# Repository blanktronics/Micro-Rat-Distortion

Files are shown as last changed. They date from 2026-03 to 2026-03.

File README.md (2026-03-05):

# Overview
Micro Rat Distortion majorly influnced by Olinthus Designs mini effects.

The idea is simple, I wanted to challenge myself by trying to recreate an extremely small version of the ProCo Rat distortion.

My secondary challenge is I want to create something even smaller than the Olinthus Desgin effects.

So far the dimesions of my project mostly mimcs the Olinthus dimensions except my assembly is 50mils wider and 50 mils thinner.

Next steps are to just shrink shrink shrink.

If you would like to try this out for yourself, the KiCad project I've designed can found in this repository!

## Pictures
Here are some pictures of the progress so far.

|  |  |  |  |
| --- | --- | --- | --- |
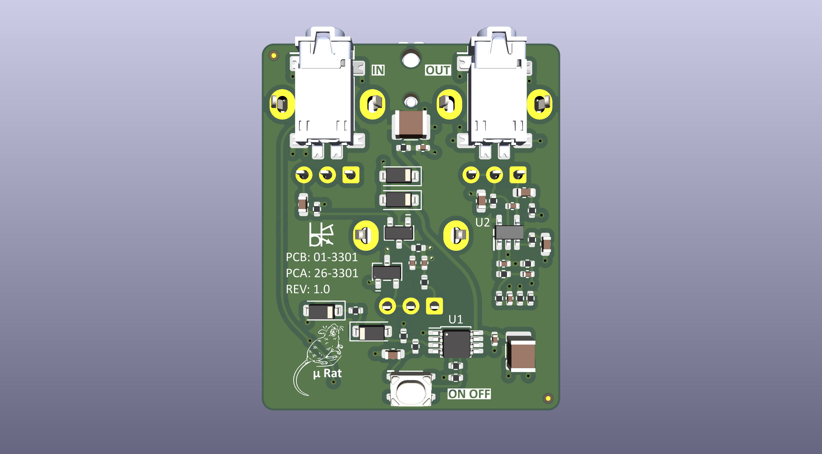
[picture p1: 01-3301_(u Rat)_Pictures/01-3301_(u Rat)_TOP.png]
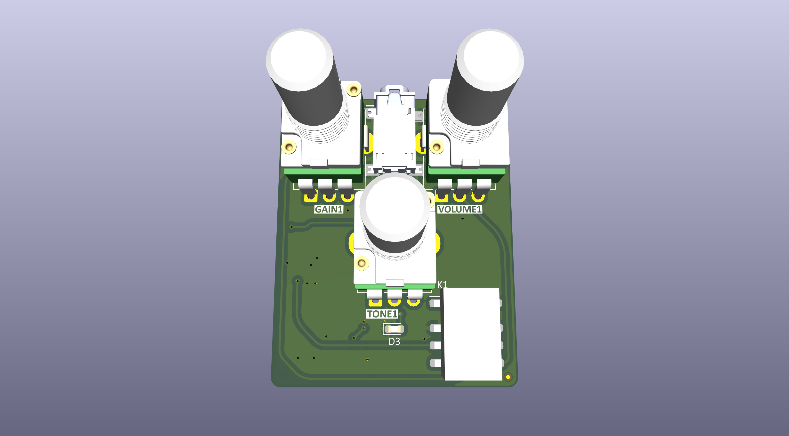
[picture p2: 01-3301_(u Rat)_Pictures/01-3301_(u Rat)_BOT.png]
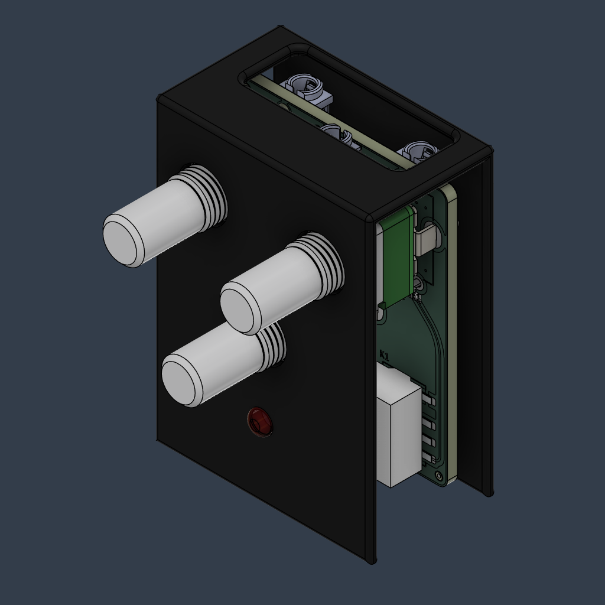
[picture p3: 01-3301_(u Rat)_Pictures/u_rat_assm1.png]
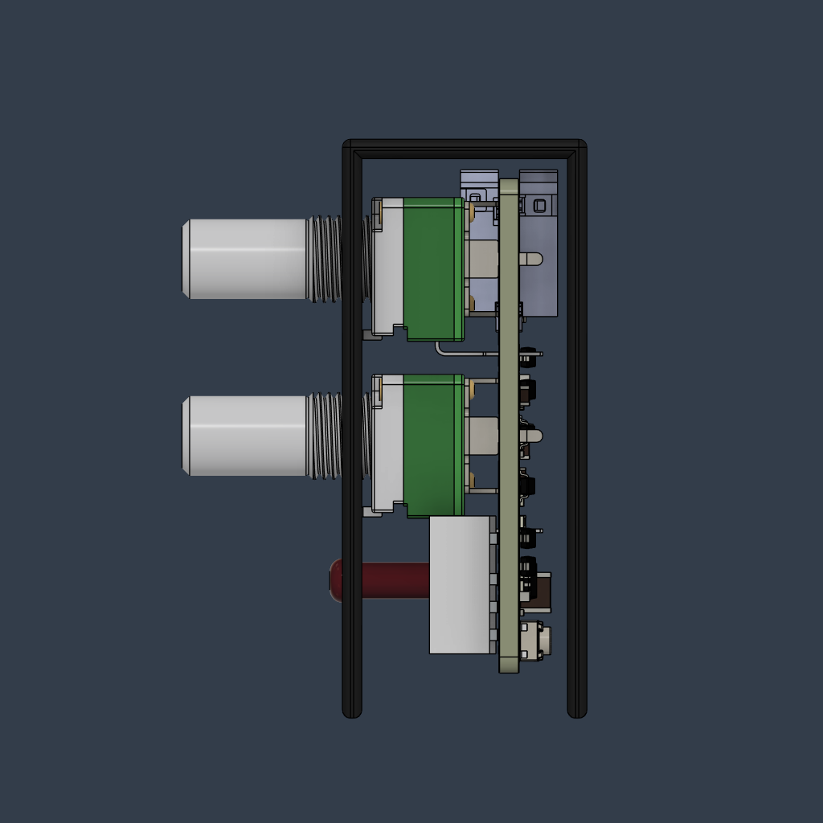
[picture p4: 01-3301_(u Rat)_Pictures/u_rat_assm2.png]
|  |  |  |  |
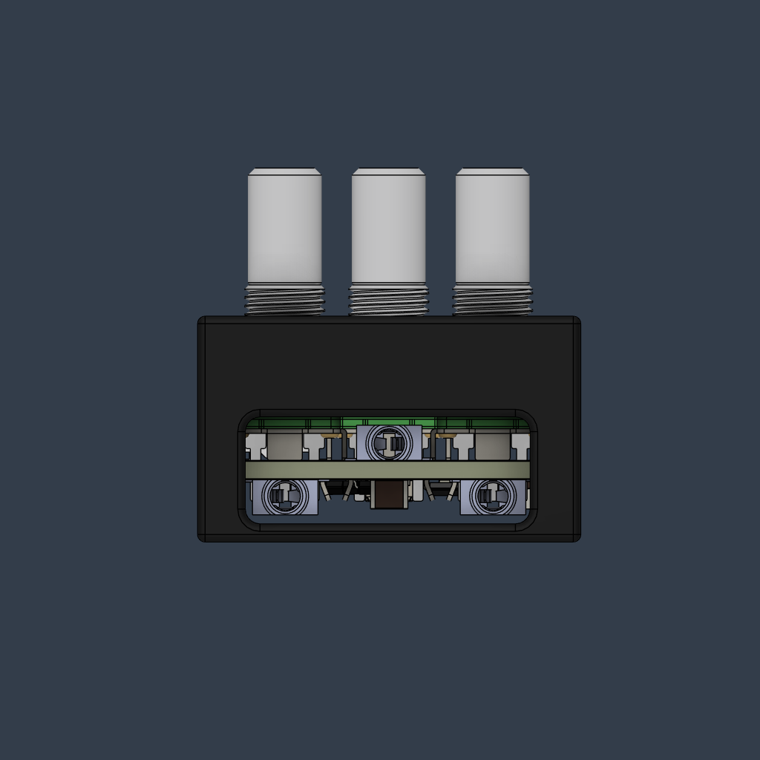
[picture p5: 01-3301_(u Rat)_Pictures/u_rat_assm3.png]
|  | |

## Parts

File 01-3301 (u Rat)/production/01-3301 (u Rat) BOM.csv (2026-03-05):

Reference | Qty | Value | DNP | Exclude from BOM | Exclude from Board | Footprint | Description
C1,C15 | 2 | 1u |  |  |  | Capacitor_SMD:C_0603_1608Metric | CAP CER 1uF +/-10% 50V X7R 0603
C2,C4 | 2 | 47u |  |  |  | Capacitor_SMD:C_1210_3225Metric | CAP CER 47uF +/-10% 16V X7R 1210
C3,C5,C6 | 3 | 100n |  |  |  | Capacitor_SMD:C_0402_1005Metric | CAP CER 100nF +/-10% 25V X7R 0402
C7,C11,C14 | 3 | 22n |  |  |  | Capacitor_SMD:C_0402_1005Metric | CAP CER 22nF +/-10% 25V X7R 0402
C8,C12 | 2 | 4u7 |  |  |  | Capacitor_SMD:C_0603_1608Metric | CAP CER 4.7uF +/-10% 25V X7R 0603
C9 | 1 | 2u2 |  |  |  | Capacitor_SMD:C_0603_1608Metric | CAP CER 2.2uF +/-10% 25V X7R 0603
C10 | 1 | 1n |  |  |  | Capacitor_SMD:C_0402_1005Metric | CAP CER 1nF +/-10% 25V X7R 0402
C13 | 1 | 3n3 |  |  |  | Capacitor_SMD:C_0402_1005Metric | CAP CER 3.3nF +/-10% 25V X7R 0402
D1,D2,D4,D5 | 4 | SM5817PL |  |  |  | Diode_SMD:D_SOD-123 | 20V 1A Schottky Diode SOD-123,~
D3 | 1 | LED |  |  |  | LED_SMD:LED_0603_1608Metric | Light emitting diode
D6 | 1 | MMBD7000 |  |  |  | Package_TO_SOT_SMD:SOT-23-3 | Dual diode, anode/center/cathode
GAIN1,TONE1,VOLUME1 | 3 | A100k |  |  |  | Potentiometer_Custom:Potentiometer_Alpha_RD901F-40-00D_Single_Vertical | Potentiometer 9mm A100k Log
J1,J2,J3 | 3 | SJ2-25404D-SMT-TR |  |  |  | SamacSys_Parts:SJ225404DSMTTR | SJ2-25404D-SMT-TR - 2.5 mm, Stereo, Right Angle, Surface Mount (SMT), 4 Conductors, 2 Internal Switches, Audio Jack Connector
K1 | 1 | UD2-5NU |  |  |  | UD25NUN | KEMET, UD2, Relays, Signal, 5 V, 220 V, 250 VAC, 1 A, 100 mOhms, 1 GOhms, 10.6mm, 6.5mm, 5.45mm
Q1 | 1 | MMBFJ201 |  |  |  | Package_TO_SOT_SMD:SOT-23 | N-Channel General Purpose Amplifier
R1,R6,R8 | 3 | 100k |  |  |  | Resistor_SMD:R_0402_1005Metric | RES SMD 100k OHM 1% 1/16W 0402
R2,R3,R17 | 3 | 10k |  |  |  | Resistor_SMD:R_0402_1005Metric | RES SMD 10k OHM 1% 1/16W 0402
R4,R13 | 2 | 47R |  |  |  | Resistor_SMD:R_0402_1005Metric | RES SMD 47 OHM 1% 1/16W 0402
R5,R12 | 2 | 560R |  |  |  | Resistor_SMD:R_0402_1005Metric | RES SMD 560 OHM 1% 1/16W 0402
R7 | 1 | 100R |  |  |  | Resistor_SMD:R_0402_1005Metric | RES SMD 100 OHM 1% 1/16W 0402
R9,R10,R16 | 3 | 1M |  |  |  | Resistor_SMD:R_0402_1005Metric | RES SMD 1M OHM 1% 1/16W 0402
R11,R14,R15 | 3 | 1k |  |  |  | Resistor_SMD:R_0402_1005Metric | RES SMD 1k OHM 1% 1/16W 0402
SW1 | 1 | SKRPANE010 |  |  |  | SamacSys_Parts:SKRPANE010 | Tactile Switches 500mOhm 1.57N 16VDC 4.2X3.2X2.5MM 50mA
U1 | 1 | LM555xMM |  |  |  | Package_SO:VSSOP-8_3x3mm_P0.65mm | Precision Timer, 555 compatible, VSSOP-8
U2 | 1 | LM321SN3T1G |  |  |  | SamacSys_Parts:SOT95P275X110-5N | Unity Gain Stable with 1.5 nF Capacitive Load; Wide Supply Voltage Range: 3 V to 32 V; Short Circuit Protected Outputs; True Differential Input Stage; Low Input Bias Currents; Internally Compensated; Single and Split Supply Operation

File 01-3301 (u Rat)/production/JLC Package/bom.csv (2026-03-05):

Designator | Footprint | Quantity | Value | LCSC Part #
C1, C15 | 0603 | 2 | 1u
C10 | 0402 | 1 | 1n
C11, C14, C7 | 0402 | 3 | 22n
C12, C8 | 0603 | 2 | 4u7
C13 | 0402 | 1 | 3n3
C2, C4 | 1210 | 2 | 47u
C3, C5, C6 | 0402 | 3 | 100n
C9 | 0603 | 1 | 2u2
D1, D2, D4, D5 | D_SOD-123 | 4 | SM5817PL
D3 | 0603 | 1 | LED
D6 | SOT-23-3 | 1 | MMBD7000
GAIN1, TONE1, VOLUME1 | Potentiometer_Alpha_RD901F-40-00D_Single_Vertical | 3 | A100k
J1, J2, J3 | SJ225404DSMTTR | 3 | SJ2-25404D-SMT-TR
K1 | UD25NUN | 1 | UD2-5NU
Q1 | SOT-23 | 1 | MMBFJ201
R1, R6, R8 | 0402 | 3 | 100k
R10, R16, R9 | 0402 | 3 | 1M
R11, R14, R15 | 0402 | 3 | 1k
R12, R5 | 0402 | 2 | 560R
R13, R4 | 0402 | 2 | 47R
R17, R2, R3 | 0402 | 3 | 10k
R7 | 0402 | 1 | 100R
SW1 | SKRPANE010 | 1 | SKRPANE010
U1 | VSSOP-8_3x3mm_P0.65mm | 1 | LM555xMM
U2 | SOT95P275X110-5N | 1 | LM321SN3T1G

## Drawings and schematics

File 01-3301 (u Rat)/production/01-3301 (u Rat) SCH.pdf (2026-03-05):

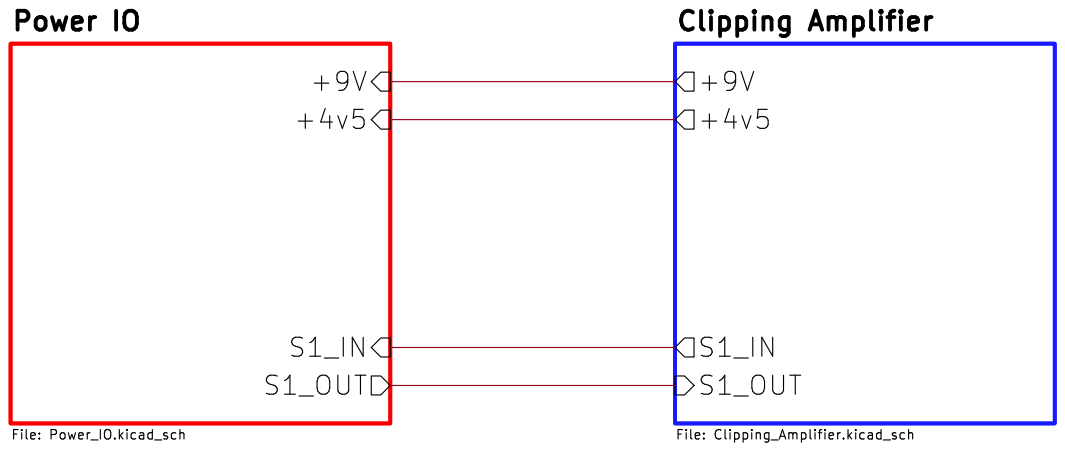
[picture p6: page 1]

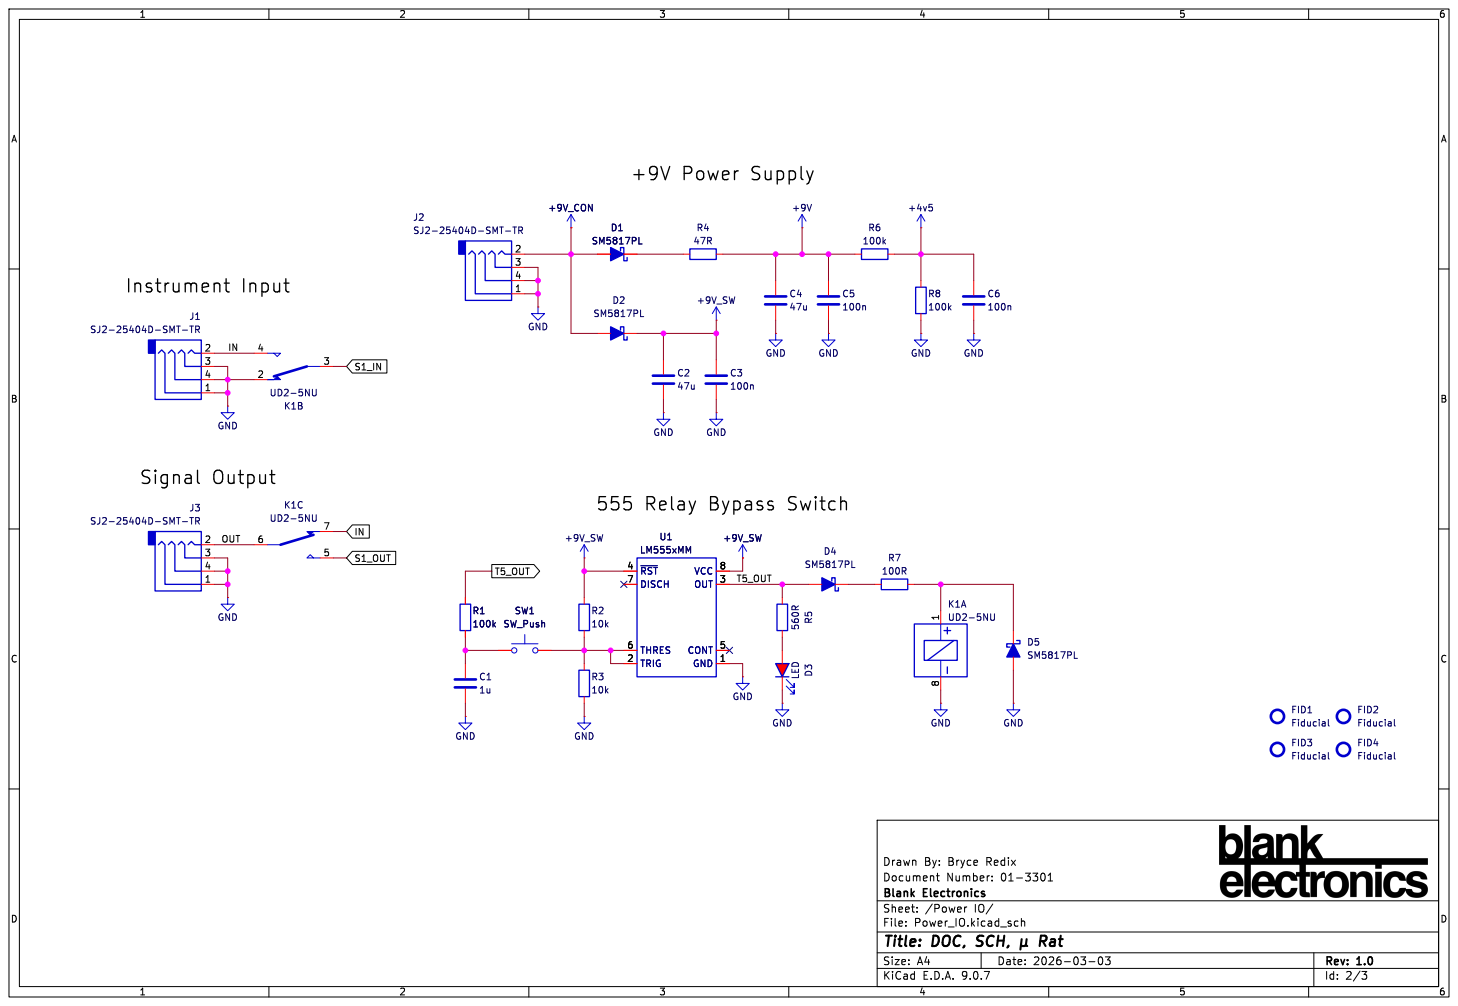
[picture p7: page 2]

J1 SJ2-25404D-SMT-TR
IN OUT Signal Output

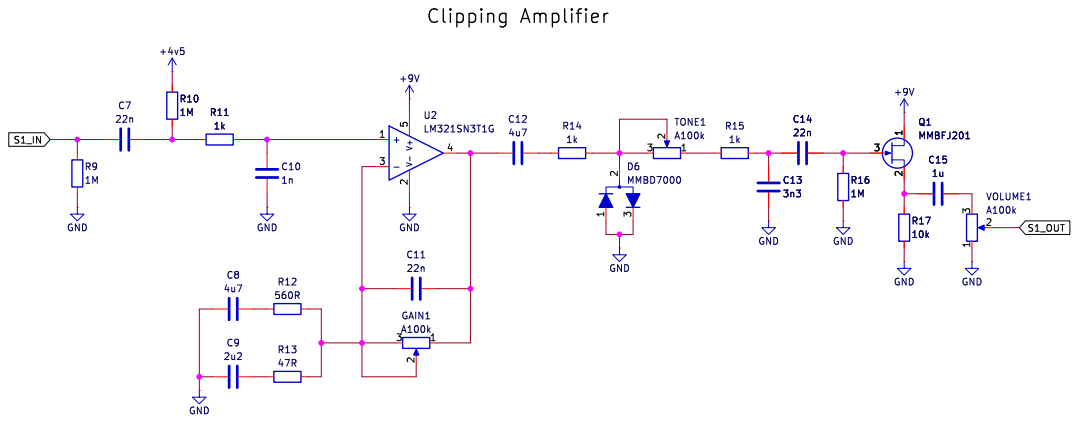
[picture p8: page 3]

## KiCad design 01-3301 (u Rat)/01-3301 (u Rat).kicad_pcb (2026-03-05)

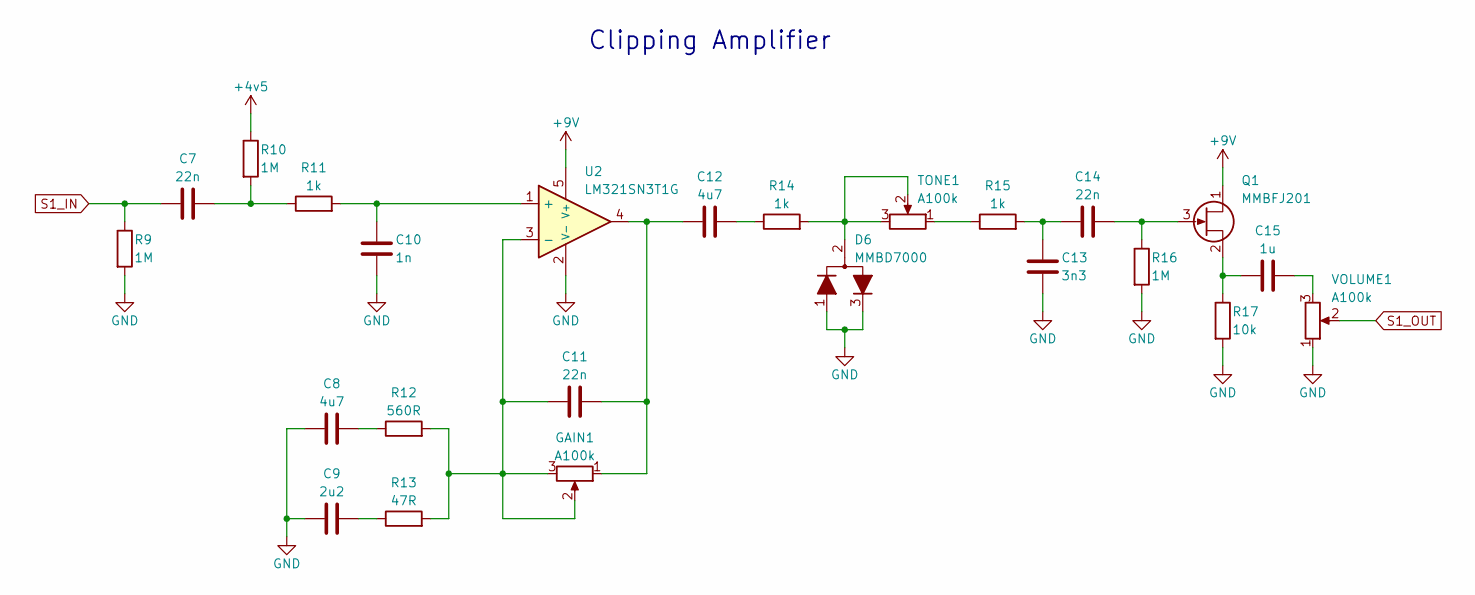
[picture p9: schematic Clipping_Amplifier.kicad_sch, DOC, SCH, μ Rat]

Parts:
C7, C11, C14: 22n; C_0402_1005Metric
C8, C12: 4u7; C_0603_1608Metric
C9: 2u2; C_0603_1608Metric
C10: 1n; C_0402_1005Metric
C13: 3n3; C_0402_1005Metric
C15: 1u; C_0603_1608Metric
D6: MMBD7000; SOT-23-3
GAIN1: A100k; Potentiometer_Alpha_RD901F-40-00D_Single_Vertical
Q1: MMBFJ201; SOT-23; Manufacturer_Part_Number MMBFJ201; Mouser Part Number 512-MMBFJ201
R9, R10, R16: 1M; R_0402_1005Metric
R11, R14, R15: 1k; R_0402_1005Metric
R12: 560R; R_0402_1005Metric
R13: 47R; R_0402_1005Metric
R17: 10k; R_0402_1005Metric
TONE1: A100k; Potentiometer_Alpha_RD901F-40-00D_Single_Vertical
U2: LM321SN3T1G; SOT95P275X110-5N; Manufacturer_Part_Number LM321SN3T1G; Mouser Part Number 863-LM321SN3T1G
VOLUME1: A100k; Potentiometer_Alpha_RD901F-40-00D_Single_Vertical

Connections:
+4v5: R10.1; also elsewhere on the board
+9V: Q1.1 (D), U2.5 (V+); also elsewhere on the board
GND: C8.1, C9.1, C10.2, C13.2, D6.1 (A), D6.3 (K), R9.2, R16.2, R17.2, U2.2 (V-), VOLUME1.1; also elsewhere on the board
unnamed: C7.2, R10.2, R11.1
unnamed: C8.2, R12.1
unnamed: C9.2, R13.1
unnamed: C11.2, C12.1, GAIN1.1, U2.4
unnamed: C12.2, R14.1
unnamed: C13.1, C14.1, R15.2
unnamed: C15.2, VOLUME1.3
unnamed: D6.2 (common), R14.2, TONE1.2, TONE1.3
unnamed: C14.2, Q1.3 (G), R16.1
unnamed: C15.1, Q1.2 (S), R17.1
unnamed: R15.1, TONE1.1
unnamed: C10.1, R11.2, U2.1 (+)
unnamed: C11.1, GAIN1.2, GAIN1.3, R12.2, R13.2, U2.3 (-)
S1_IN: C7.1, R9.1; also elsewhere on the board
S1_OUT: VOLUME1.2; also elsewhere on the board

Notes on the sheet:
Clipping Amplifier

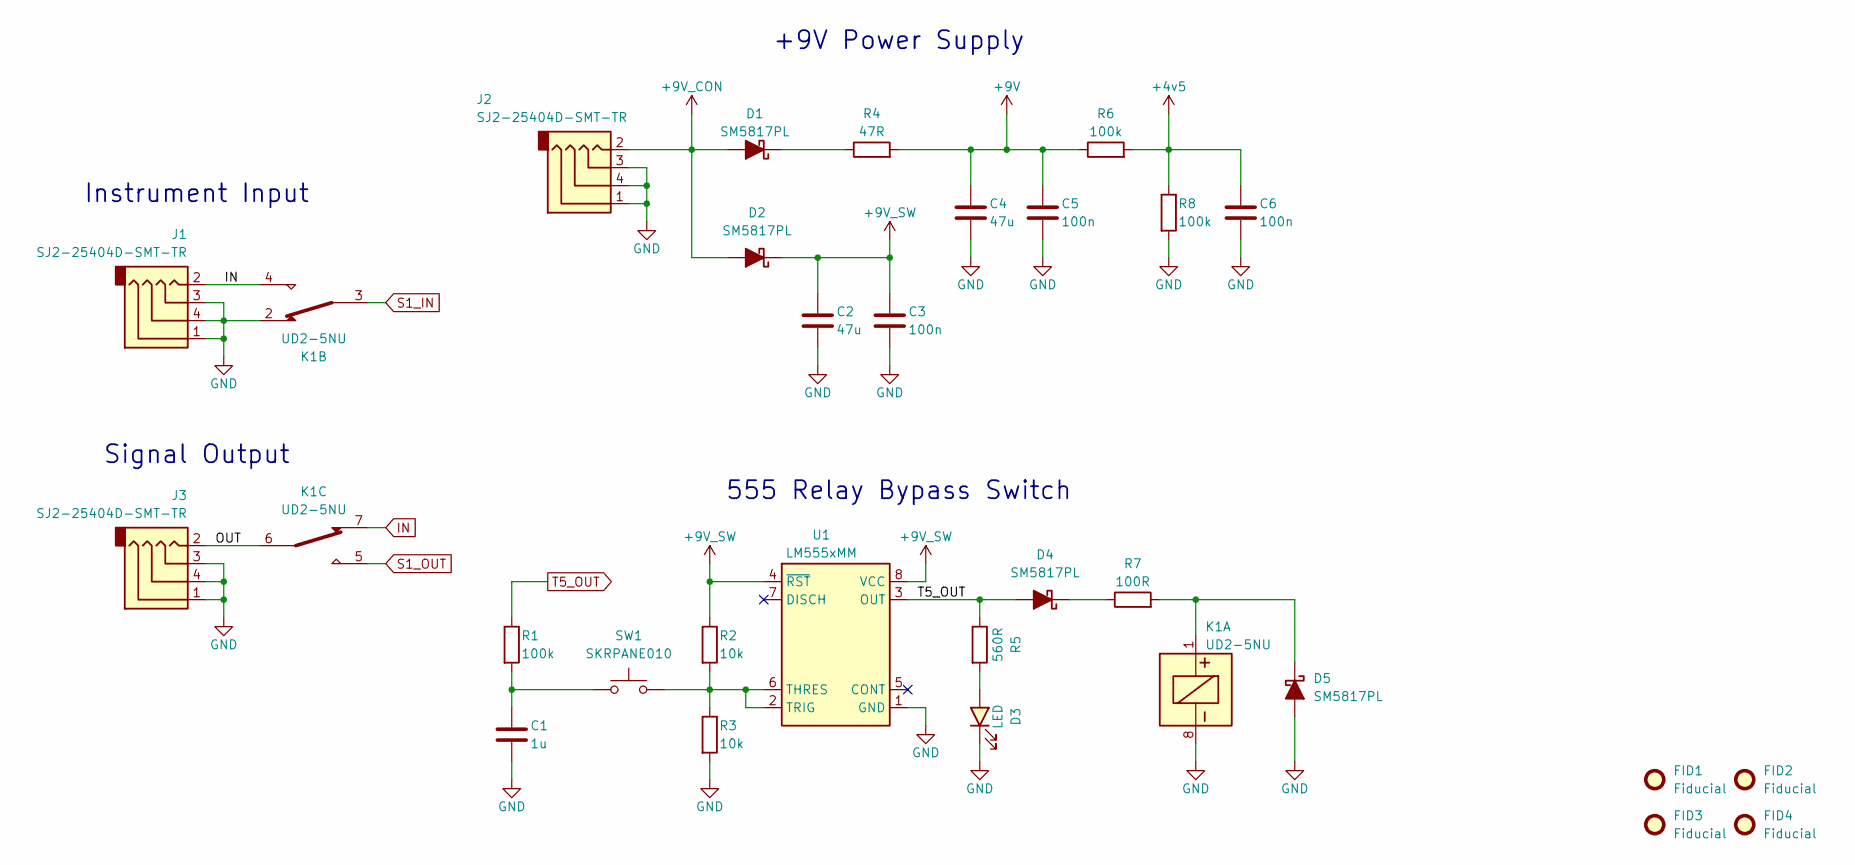
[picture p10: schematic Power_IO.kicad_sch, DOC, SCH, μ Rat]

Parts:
C1: 1u; C_0603_1608Metric
C2, C4: 47u; C_1210_3225Metric
C3, C5, C6: 100n; C_0402_1005Metric
D1, D2, D4, D5: SM5817PL; D_SOD-123
D3: LED; LED_0603_1608Metric
FID1, FID2, FID3, FID4: Fiducial; Fiducial_0.5mm_Mask1mm
J1, J2, J3: SJ2-25404D-SMT-TR; SJ225404DSMTTR; Manufacturer_Part_Number SJ2-25404D-SMT-TR; Mouser Part Number 490-SJ2-25404DSMT-TR
K1: UD2-5NU; UD25NUN; Manufacturer_Part_Number UD2-5NU; Mouser Part Number 551-UD2-5NU
R1, R6, R8: 100k; R_0402_1005Metric
R2, R3: 10k; R_0402_1005Metric
R4: 47R; R_0402_1005Metric
R5: 560R; R_0402_1005Metric
R7: 100R; R_0402_1005Metric
SW1: SKRPANE010
U1: LM555xMM; VSSOP-8_3x3mm_P0.65mm

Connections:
+4v5: C6.1, R6.2, R8.1; also elsewhere on the board
+9V: C4.1, C5.1, R4.2, R6.1; also elsewhere on the board
+9V_CON: D1.2 (A), D2.2 (A), J2.2 (TIP)
+9V_SW: C2.1, C3.1, D2.1 (K), R2.1, U1.4 (~RST), U1.8 (VCC)
/Power IO/OUT: J3.2 (TIP), K1.6 (COM_2)
GND: C1.2, C2.2, C3.2, C4.2, C5.2, C6.2, D3.1 (K), D5.2 (A), J1.1 (SLEEVE), J1.3 (RING1), J1.4 (RING2), J2.1 (SLEEVE), J2.3 (RING1), J2.4 (RING2), J3.1 (SLEEVE), J3.3 (RING1), J3.4 (RING2), K1.2 (NC_1), K1.8 (COIL_-), R3.2, R8.2, U1.1 (GND); also elsewhere on the board
IN: J1.2 (TIP), K1.4 (NO_1), K1.7 (NC_2)
unnamed: C1.1, R1.2, SW1.1
unnamed: D1.1 (K), R4.1
unnamed: D3.2 (A), R5.2
unnamed: D4.1 (K), R7.1
unnamed: D5.1 (K), K1.1 (COIL_+), R7.2
unnamed: R2.2, R3.1, SW1.2, U1.2 (TRIG), U1.6 (THRES)
S1_IN: K1.3 (COM_1); also elsewhere on the board
S1_OUT: K1.5 (NO_2); also elsewhere on the board
T5_OUT: D4.2 (A), R1.1, R5.1, U1.3 (OUT)

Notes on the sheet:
555 Relay Bypass Switch
Instrument Input
Signal Output
+9V Power Supply

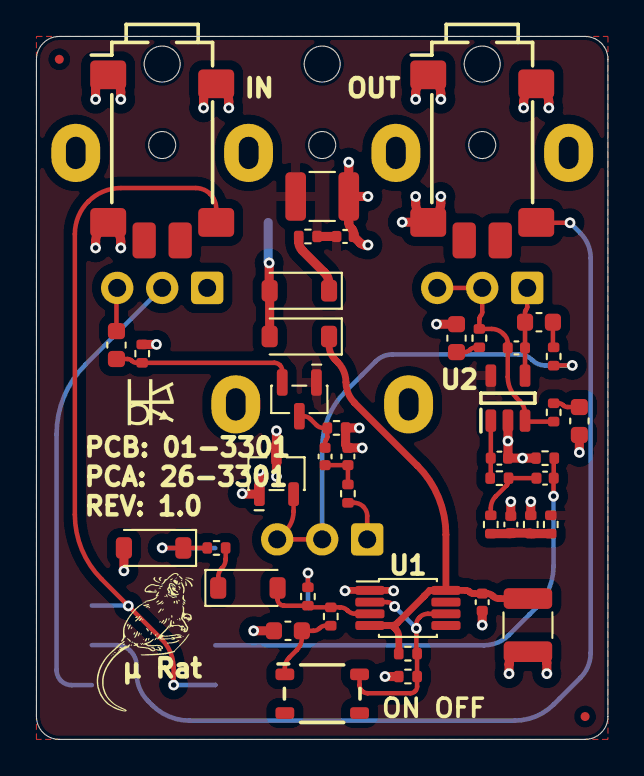
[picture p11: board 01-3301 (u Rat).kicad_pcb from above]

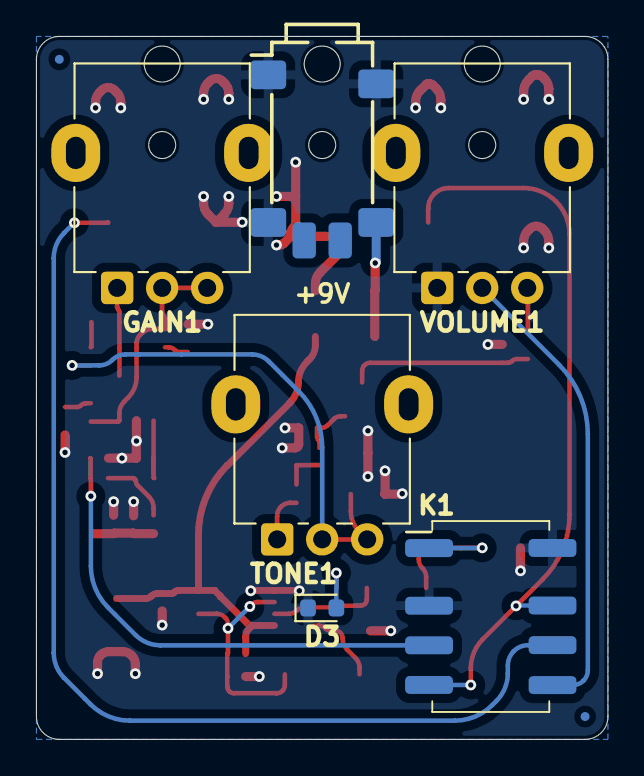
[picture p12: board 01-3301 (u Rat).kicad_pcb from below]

Board: 2 copper layers, 31.8 x 39.1 mm, 53 parts (8 on the bottom side), 29 nets.
